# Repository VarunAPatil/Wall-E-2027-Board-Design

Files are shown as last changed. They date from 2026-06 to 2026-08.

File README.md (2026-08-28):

# Wall-E-2027-Board-Design

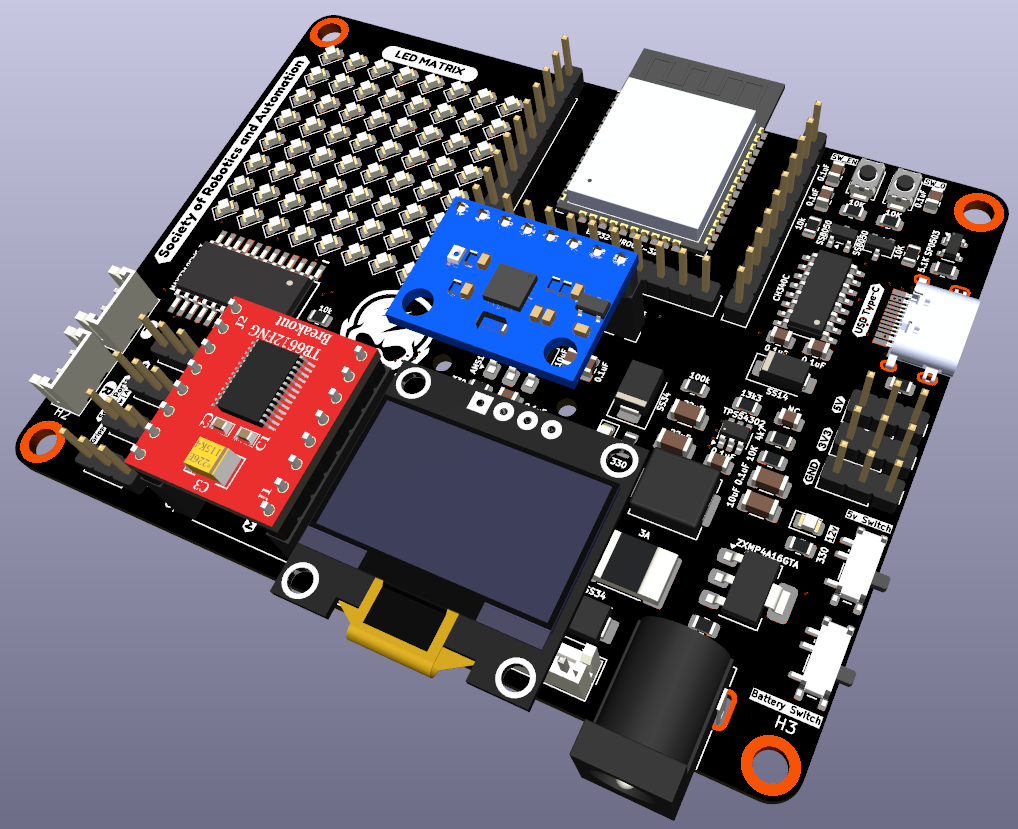
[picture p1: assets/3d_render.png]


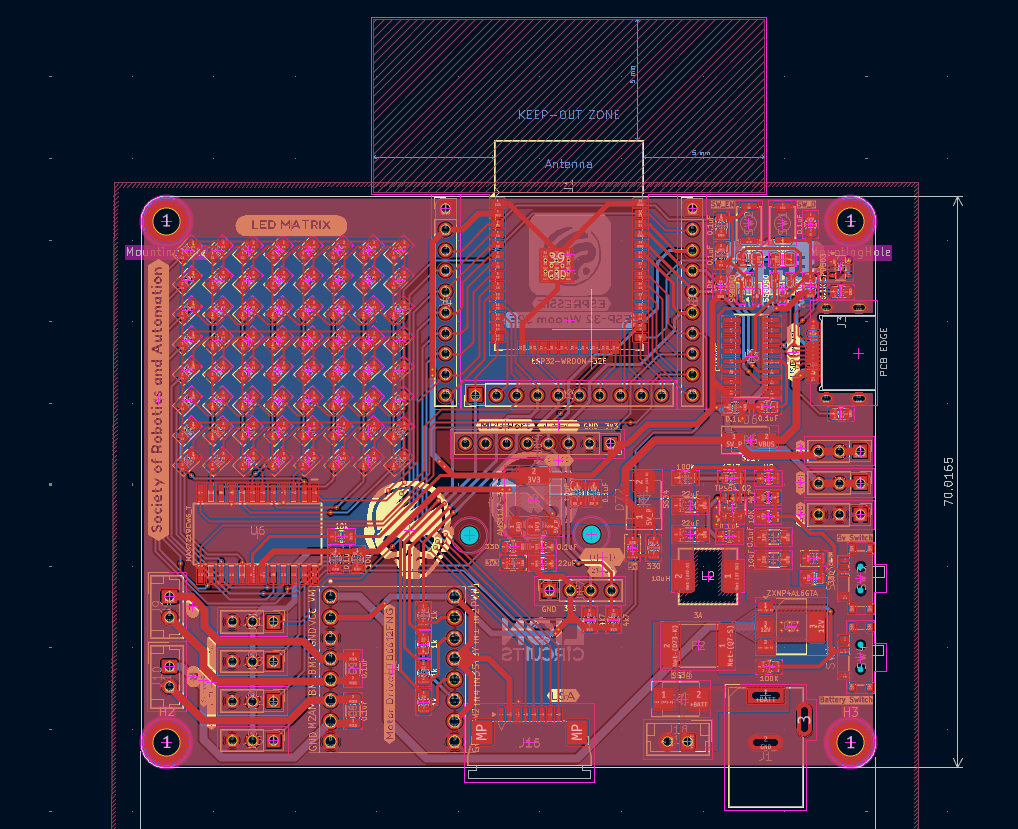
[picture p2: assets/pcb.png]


<!-- PROJECT LOGO -->

[][stars-url]
[][forks-url]
[][issues-url]
[][license-url]

# SRA Board

The SRA board is a development board based on ESP32 with on-board peripherals like a programmable LED matrix, switches, sensor ports for Line Sensor Array and MPU-6050, protection circuit for over-current and reverse voltage, and motor drivers.

## About the Project

- This development board is used for the [Wall-E](https://github.com/SRA-VJTI/Wall-E) and [MARIO](https://github.com/SRA-VJTI/MARIO) workshops conducted by [SRA](https://github.com/SRA-VJTI).
- Designed using KiCAD.

## Getting Started with a Development Board

In general, every development board has the following basic features:

- ### Power Supply Unit
  - Microcontrollers (MCUs) usually run on 3.3V or 5V logic supply voltage while input to a development board is normally 12V for motor and driving/controlling peripheral devices.
  - So, in order to have a single input source, a _power_ section which inter converts this 12V to standard levels like 5V & 3.3V for MCU and sensors is present.This is achieved using a step-down [buck regulator](https://www.youtube.com/watch?v=m8rK9gU30v4).

- ### Motor Driver
  - Motors usually run on 12V and MCU output is generally 5V/3.3V. So, an external motor driver circuitry is required to control motors according to the MCU input.
  - The SRA board use the [TB6612FNG](./datasheets/TB6612FNG_motor_driver.pdf) Motor Driver, which is a MOS-based H-Bridge motor driver.

- ### Sensor Port
  - According to the external sensor types, usually development boards have onboard sensor ports where the sensors can be connected easily. [LSA - Line Sensor Array]() and [MPU- Motion Processing Unit]() have on-board connection ports.
  - Easily available and efficient [JST XH connectors](https://en.wikipedia.org/wiki/JST_connector).
  - Previous versions used bulky [FRC connectors](<https://www.sunrom.com/c/frc-idc-flat-cable-box-header#:~:text=FRC%20(Flat%20Ribon%20Cable)%20are,from%206%20to%2064%20pins.>)

- ### Protection against [Reverse Voltage](https://www.google.com/url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)
  - The SRA Boards use diodes for reverse voltage protection in the power-line.
  - 12V Motor line and power regulated line have been separated with [SS34](./datasheets/ss34_3A_schottky_diode.pdf) and [SS54](./datasheets/ss24_2A_schottky_diode.pdf) schottky diodes respectively.

- ### Protection against [Over Current](https://www.baypower.com/blog/what-is-overcurrent-protection/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,of%20a%20piece%20of%20equipment.)
  - This is done by PTC Resettable Fuses.
- ### Programmable Switches and LEDs
  - Every development board should have some programmable switches and LEDs for testing, control and debugging purposes.
  - The SRA Board features a 8x8 LED matrix (64 LEDs total) controlled via MAX7219, which provides enhanced debugging capabilities and expressive visual feedback while reducing GPIO usage compared to discrete LEDs.

- ### Power Switch
  - All versions have a power switch for the motor driver, using which power supply to the motor driver can be toggled. Similarly, there was a switch for the ESP32 MCU.

- ### **Compatiblity of SRA Board with Battery [3- 3.3V 2500mAh Batteries](https://robu.in/product/bak-nmc-18650-2500mah-8c-lithium-ion-battery/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)**
  - The SRA Board is compatible with **3-cell (3S) Lithium-ion battery packs** which use an external **[BMS (Battery Management System)](https://robu.in/product/3s-10a-12v-18650-lithium-battery-charger-board-protection-module/)**.
  - The BMS helps maintain safe operating voltages and disconnects the battery when the voltage drops below a safe limit.
  - It also ensures balanced charging and discharging of the three cells, improving the overall health and lifetime of the battery pack.

- ### **LD33 (3.3V) to [AMS1117](http://www.advanced-monolithic.com/pdf/ams1117.pdf)**:
  - Older editions used the **LD33 IC** to step down from 5V to 3.3V.
  - This was later replaced with the **AMS1117-3.3 LDO**, which is more compact and widely used for stable 3.3V regulation.
  - (_AMS1117 is also used on the ESP32-DevKitC V4 module._)

- ### **Reverse voltage protection: Diodes to P-MOSFET**
  - Diodes placed in series with the power line introduce voltage drop and power loss compared to a **P-MOSFET based protection circuit**.
  - Due to the higher current requirements of the motors, managing diode size and current rating became difficult.
  - Therefore, earlier versions used a **P-MOSFET based reverse polarity protection circuit**, which is more efficient and can handle higher currents.

## Contributors

- [Varun Patil](https://github.com/VarunAPatil): _Designer_
- [Omkar Nanajkar](https://github.com/nomkar24): _Designer_
<!-- ACKNOWLEDGEMENTS AND REFERENCES -->

## License

- Distributed under the [MIT License](https://github.com/SRA-VJTI/sraboard-hardware-design/blob/master/LICENSE).

[forks-shield]: https://img.shields.io/github/forks/SRA-VJTI/sra-board-hardware-design
[forks-url]: https://github.com/SRA-VJTI/sra-board-hardware-design/network/members
[stars-shield]: https://img.shields.io/github/stars/SRA-VJTI/sra-board-hardware-design
[stars-url]: https://github.com/SRA-VJTI/sra-board-hardware-design/stargazers
[issues-shield]: https://img.shields.io/github/issues/SRA-VJTI/sra-board-hardware-design
[issues-url]: https://github.com/SRA-VJTI/sra-board-hardware-design/issues
[license-shield]: https://img.shields.io/github/license/SRA-VJTI/sra-board-hardware-design
[license-url]: https://github.com/SRA-VJTI/sra-board-hardware-design/blob/master/LICENSE

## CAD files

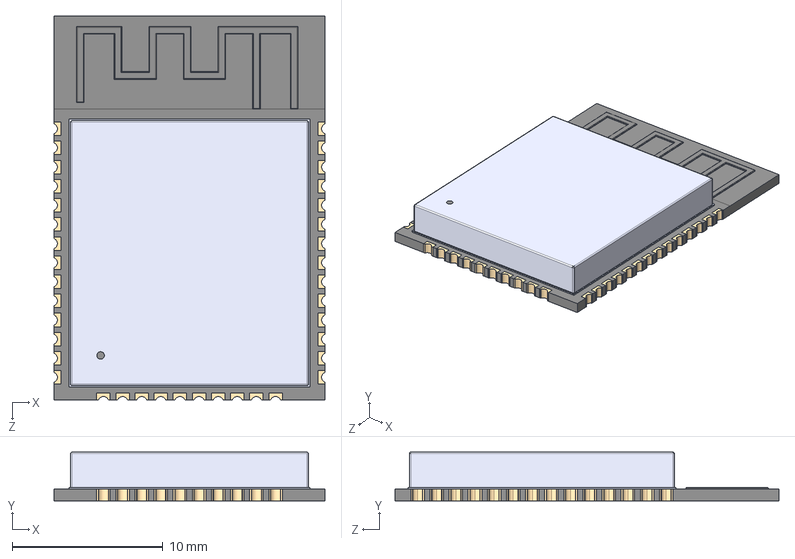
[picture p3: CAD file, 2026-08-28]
3D/ESP32-WROOM-32E.STEP
18.0 x 3.25 x 25.5 mm

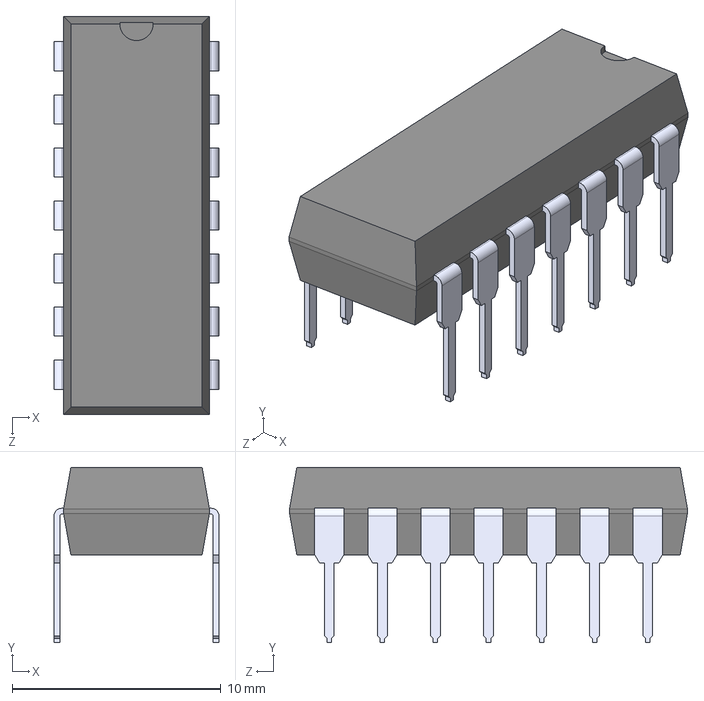
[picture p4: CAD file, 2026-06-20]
MAX7219/MAX7219.step
7.90 x 8.38 x 19.1 mm

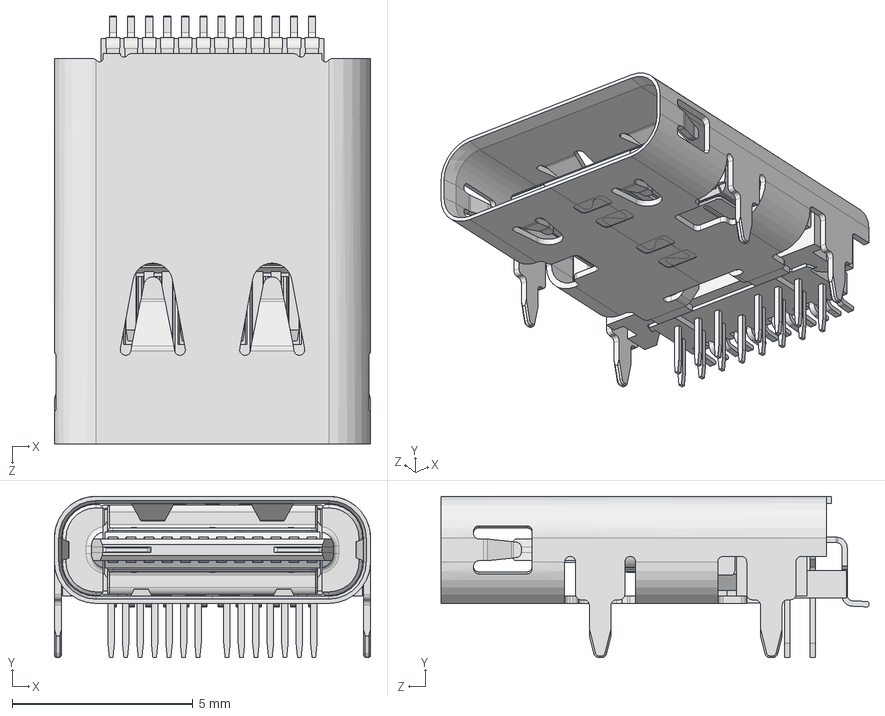
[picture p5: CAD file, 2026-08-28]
3D/217B-AG01--3DModel-STEP-1070261.STEP
8.74 x 4.46 x 11.8 mm

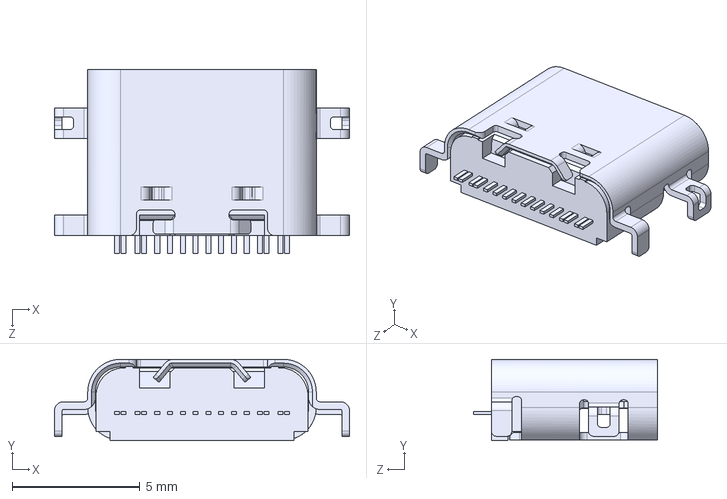
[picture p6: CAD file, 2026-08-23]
3D/GSB1C4621DS1HR.step
11.5 x 3.18 x 7.20 mm

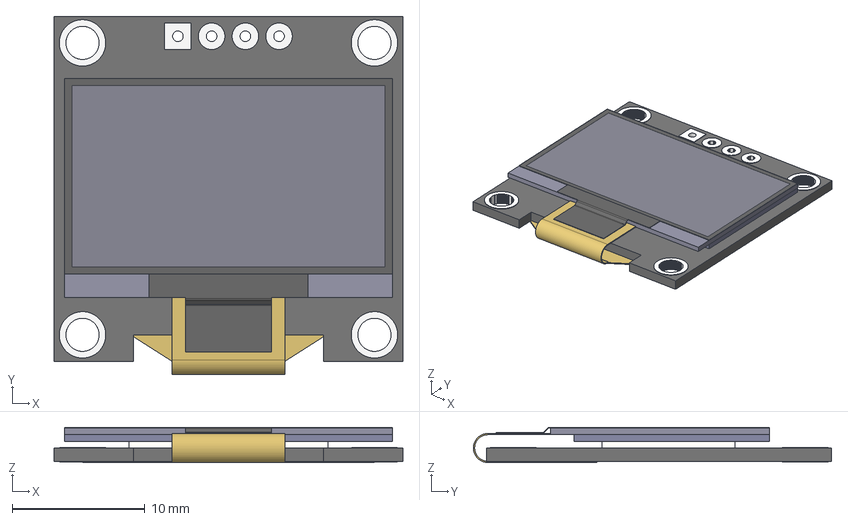
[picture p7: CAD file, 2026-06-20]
3D/OLED.step
26.3 x 27.0 x 2.65 mm
Body - PCB
Body - Back Panel
Body - Adhesive Pad
Body - Front Panel
Body - Flex Connector Bend
Body - Flex Connector Terminals
Body - Black Tape
Body - Protective Foil
Body - Screen Border
Extrude - Annular Rings

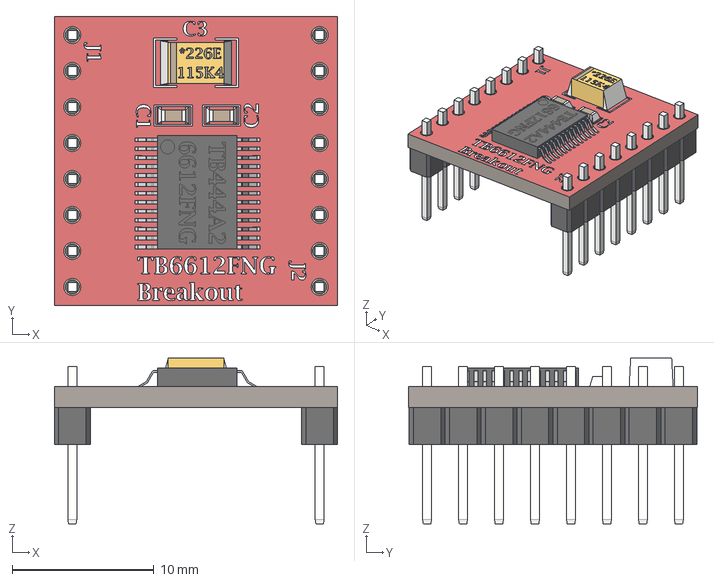
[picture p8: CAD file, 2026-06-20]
3D/MotorDriver.step
20.0 x 20.4 x 11.7 mm
8x1 male header pins x 2

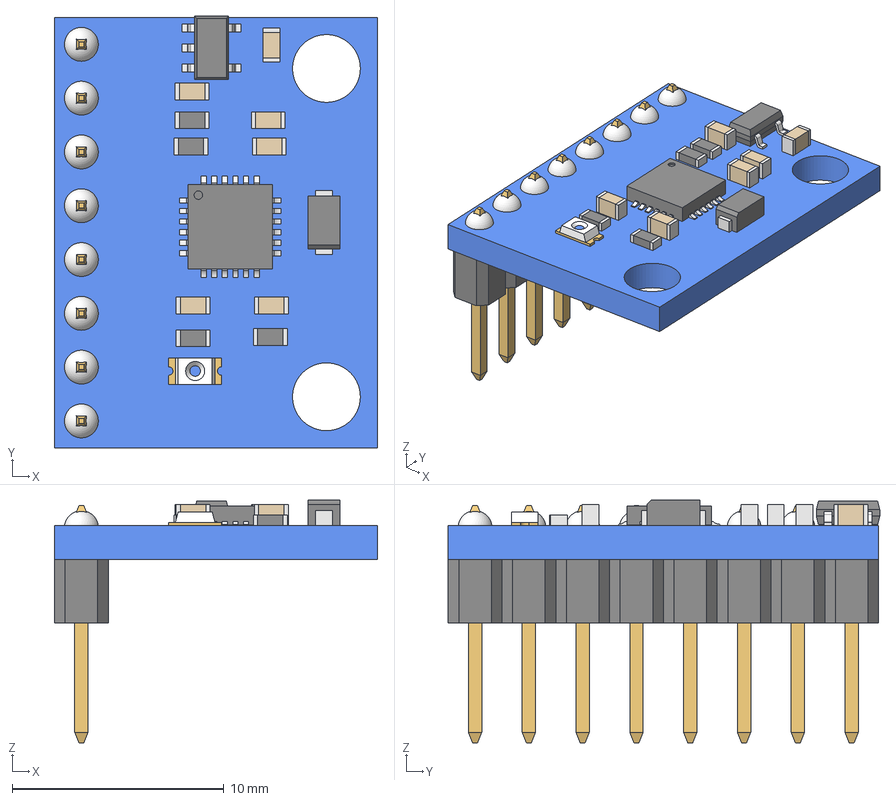
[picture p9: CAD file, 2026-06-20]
3D/MPU6050Module.step
15.3 x 20.4 x 11.5 mm
Board_001
SOT25_001
0603 Capacitor_001
0603 Capacitor_002
0603 Capacitor_003
0603 Capacitor_004
0603 Capacitor_005
0603 Capacitor_006
0603 Resistor_001
0603 Resistor_002
0603 Resistor_003
0603 Resistor_004
SM LED_001
Diode 2_001
24 QFN_001
1x8 Male Header_001

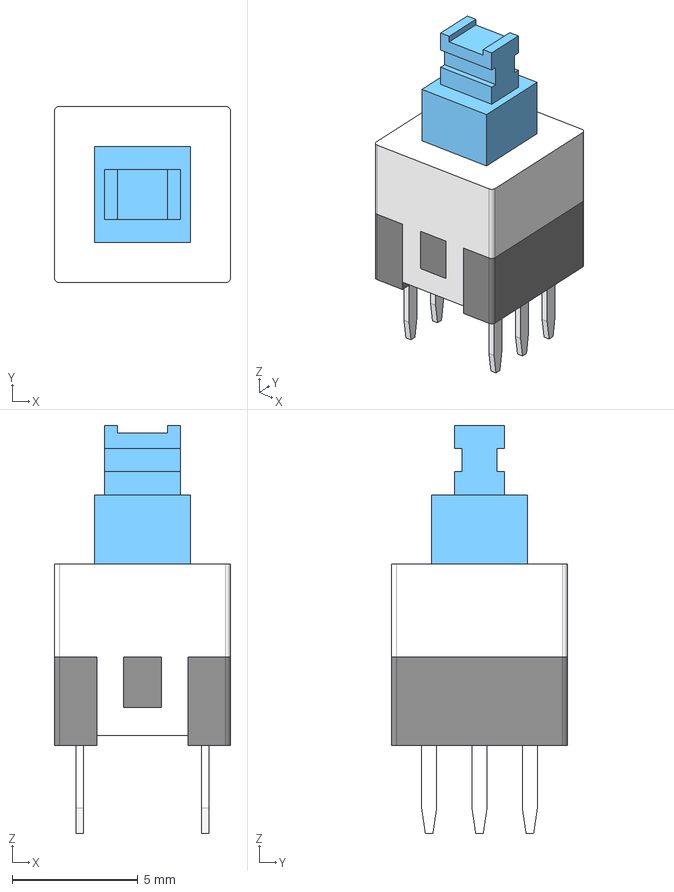
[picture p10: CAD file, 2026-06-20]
3D/DPDTSwitch.step
7.00 x 7.00 x 16.2 mm

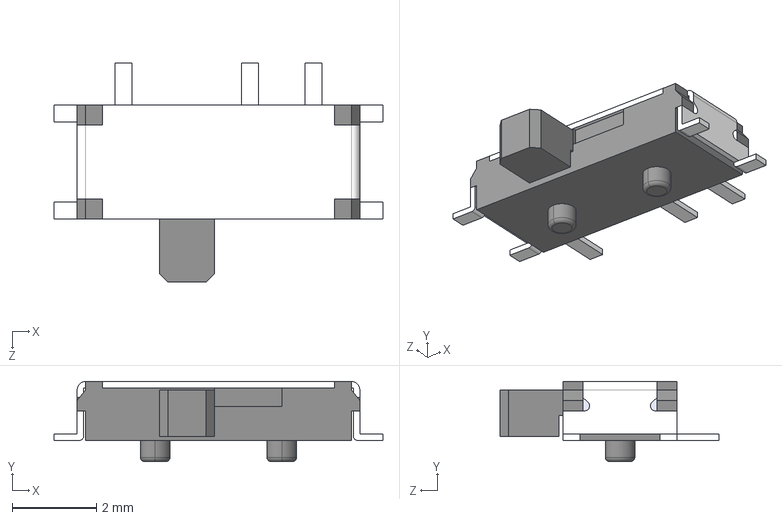
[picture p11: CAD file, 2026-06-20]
3D/MSK12C02.stp
7.80 x 1.90 x 5.20 mm

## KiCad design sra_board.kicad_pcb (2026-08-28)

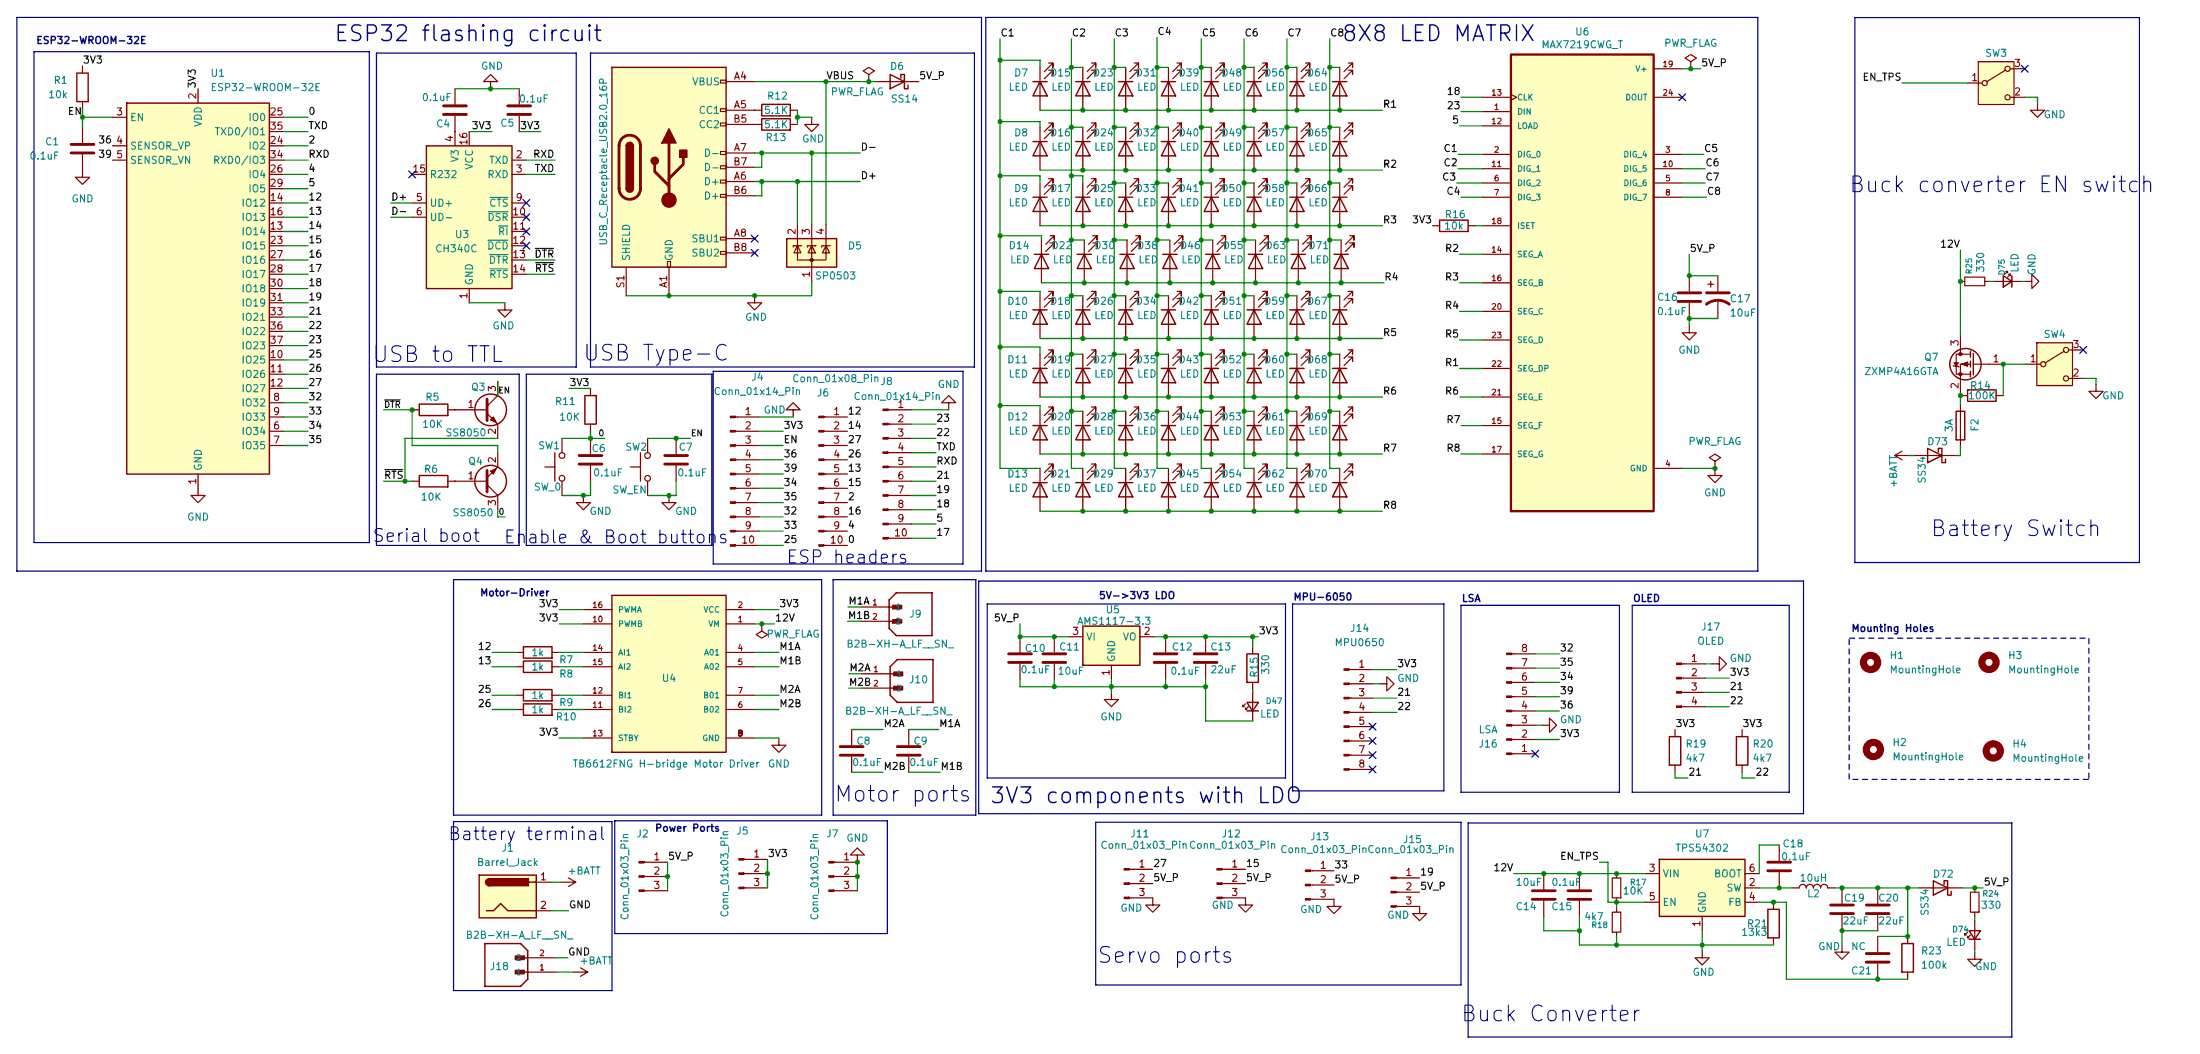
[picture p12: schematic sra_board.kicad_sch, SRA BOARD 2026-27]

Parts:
C1, C4, C5, C6, C7, C10, C12, C16, C18: 0.1uF; C_0805_2012Metric
C8, C9, C15: 0.1uF; C_1206_3216Metric
C11, C17: 10uF; C_0805_2012Metric
C13: 22uF; C_0805_2012Metric
C14: 10uF; C_1206_3216Metric
C19, C20: 22uF; C_1206_3216Metric
C21: NC; C_0805_2012Metric
D5: SP0503; SOT-143
D6: SS14; D_SMA
D7, D8, D9, D10, D11, D12, D13, D14, D15, D16, D17, D18, D19, D20, D21, D22, D23, D24, D25, D26, D27, D28, D29, D30, D31, D32, D33, D34, D35, D36, D37, D38, D39, D40, D41, D42, D43, D44, D45, D46, D47, D48, D49, D50, D51, D52, D53, D54, D55, D56, D57, D58, D59, D60, D61, D62, D63, D64, D65, D66, D67, D68, D69, D70, D71, D74, D75: LED; LED_0805_2012Metric
D72, D73: SS34; D_SMB
F2: 3A; Fuse_2920_7451Metric
H1, H2, H3, H4: MountingHole; MountingHole_3.2mm_M3_DIN965_Pad_TopOnly
J1: Barrel_Jack; BarrelJack_Wuerth_6941xx301002
J2, J5, J7, J11, J12, J13, J15: Conn_01x03_Pin; PinHeader_1x03_P2.54mm_Vertical
J3: USB_C_Receptacle_USB2.0_16P; AMPHENOL_GSB1C4621DS1HR
J4, J8: Conn_01x14_Pin; PinHeader_1x10_P2.54mm_Vertical
J6: Conn_01x08_Pin; PinHeader_1x10_P2.54mm_Vertical
J9, J10, J18: B2B-XH-A_LF__SN_; JST_EH_B2B-EH-A_1x02_P2.50mm_Vertical; PARTREV N/A
J14: MPU0650; PinSocket_1x08_P2.54mm_Vertical
J16: LSA; JUSHUO_AFA07-S08FCA-00_1x8-1MP_P1.0mm_Horizontal
J17: OLED; PinSocket_1x04_P2.54mm_Vertical
L2: 10uH; L_Sunlord_MWSA0603S
Q3, Q4: SS8050; SOT-23
Q7: ZXMP4A16GTA; SOT-223
R1, R16: 10k; R_0805_2012Metric
R5, R6, R11, R17: 10K; R_0805_2012Metric
R7, R8, R9, R10: 1k; R_0805_2012Metric
R12, R13: 5.1K; R_0805_2012Metric
R14: 100K; R_0805_2012Metric
R15, R24, R25: 330; R_0805_2012Metric
R18, R19, R20: 4k7; R_0805_2012Metric
R21: 13k3; R_0805_2012Metric
R23: 100k; R_0805_2012Metric
SW1: SW_0; SW_Push_SPST_NO_Alps_SKRK
SW2: SW_EN; SW_Push_SPST_NO_Alps_SKRK
SW3, SW4: SW_Wuerth_450301014042; SW_SPDT_Shouhan_MSK12C02
U1: ESP32-WROOM-32E; ESP32-WROOM-32D
U3: CH340C; SOIC-16_3.9x9.9mm_P1.27mm
U4: TB6612FNG H-bridge Motor Driver; MODULE_ROB-14450
U5: AMS1117-3.3; SOT-223-3_TabPin2
U6: MAX7219CWG_T; SOIC24
U7: TPS54302; SOT-23-6

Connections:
+BATT: D73.2 (A), J1.1, J18.1
/0: C6.2, J6.10, Q4.3, R11.1, SW1.2, U1.25 (IO0)
/2: J6.7, U1.24 (IO2)
/3V3: C5.1, C12.1, C13.1, J4.2, J5.1, J5.2, J5.3, J14.1, J16.2, J17.2, R1.1, R11.2, R15.1, R16.1, R19.1, R20.1, U1.2 (VDD), U3.16 (VCC), U4.2 (VCC), U4.10 (PWMB), U4.13 (STBY), U4.16 (PWMA), U5.2 (VO)
/4: J6.9, U1.26 (IO4)
/5: J8.9, U1.29 (IO5), U6.12 (LOAD)
/5V_P: C10.1, C11.1, C16.1, C17.1, D6.1 (K), D72.1 (K), J2.1, J2.2, J2.3, J11.2, J12.2, J13.2, J15.2, R24.2, U5.3 (VI), U6.19 (V+)
/12: J6.1, R7.1, U1.14 (IO12)
/12V: C14.1, C15.1, Q7.3 (D), R17.2, R25.2, U4.1 (VM), U7.3 (VIN)
/13: J6.5, R8.1, U1.16 (IO13)
/14: J6.2, U1.13 (IO14)
/15: J6.6, J12.1, U1.23 (IO15)
/16: J6.8, U1.27 (IO16)
/17: J8.10, U1.28 (IO17)
/18: J8.8, U1.30 (IO18), U6.13 (CLK)
/19: J8.7, J15.1, U1.31 (IO19)
/21: J8.6, J14.3, J17.3, R19.2, U1.33 (IO21)
/22: J8.3, J14.4, J17.4, R20.2, U1.36 (IO22)
/23: J8.2, U1.37 (IO23), U6.1 (DIN)
/25: J4.10, R9.1, U1.10 (IO25)
/26: J6.4, R10.1, U1.11 (IO26)
/27: J6.3, J11.1, U1.12 (IO27)
/32: J4.8, J16.8, U1.8 (IO32)
/33: J4.9, J13.1, U1.9 (IO33)
/34: J4.6, J16.6, U1.6 (IO34)
/35: J4.7, J16.7, U1.7 (IO35)
/36: J4.4, J16.4, U1.4 (SENSOR_VP)
/39: J4.5, J16.5, U1.5 (SENSOR_VN)
/C1: D7.1 (K), D8.1 (K), D9.1 (K), D10.1 (K), D11.1 (K), D12.1 (K), D13.1 (K), D14.1 (K), U6.2 (DIG_0)
/C2: D15.1 (K), D16.1 (K), D17.1 (K), D18.1 (K), D19.1 (K), D20.1 (K), D21.1 (K), D22.1 (K), U6.11 (DIG_1)
/C3: D23.1 (K), D24.1 (K), D25.1 (K), D26.1 (K), D27.1 (K), D28.1 (K), D29.1 (K), D30.1 (K), U6.6 (DIG_2)
/C4: D31.1 (K), D32.1 (K), D33.1 (K), D34.1 (K), D35.1 (K), D36.1 (K), D37.1 (K), D38.1 (K), U6.7 (DIG_3)
/C5: D39.1 (K), D40.1 (K), D41.1 (K), D42.1 (K), D43.1 (K), D44.1 (K), D45.1 (K), D46.1 (K), U6.3 (DIG_4)
/C6: D48.1 (K), D49.1 (K), D50.1 (K), D51.1 (K), D52.1 (K), D53.1 (K), D54.1 (K), D55.1 (K), U6.10 (DIG_5)
/C7: D56.1 (K), D57.1 (K), D58.1 (K), D59.1 (K), D60.1 (K), D61.1 (K), D62.1 (K), D63.1 (K), U6.5 (DIG_6)
/C8: D64.1 (K), D65.1 (K), D66.1 (K), D67.1 (K), D68.1 (K), D69.1 (K), D70.1 (K), D71.1 (K), U6.8 (DIG_7)
/D+: D5.2 (K), J3.A6 (D+), J3.B6 (D+), U3.5 (UD+)
/D-: D5.3 (K), J3.A7 (D-), J3.B7 (D-), U3.6 (UD-)
/EN: C1.1, C7.2, J4.3, Q3.3, R1.2, SW2.2, U1.3 (EN)
/EN_TPS: R17.1, R18.2, SW3.1 (B), U7.5 (EN)
/M1A: C9.1, J9.1, U4.4 (A01)
/M1B: C9.2, J9.2, U4.5 (A02)
/M2A: C8.1, J10.1, U4.7 (B01)
/M2B: C8.2, J10.2, U4.6 (B02)
/R1: D7.2 (A), D15.2 (A), D23.2 (A), D31.2 (A), D39.2 (A), D48.2 (A), D56.2 (A), D64.2 (A), U6.22 (SEG_DP)
/R2: D8.2 (A), D16.2 (A), D24.2 (A), D32.2 (A), D40.2 (A), D49.2 (A), D57.2 (A), D65.2 (A), U6.14 (SEG_A)
/R3: D9.2 (A), D17.2 (A), D25.2 (A), D33.2 (A), D41.2 (A), D50.2 (A), D58.2 (A), D66.2 (A), U6.16 (SEG_B)
/R4: D14.2 (A), D22.2 (A), D30.2 (A), D38.2 (A), D46.2 (A), D55.2 (A), D63.2 (A), D71.2 (A), U6.20 (SEG_C)
/R5: D10.2 (A), D18.2 (A), D26.2 (A), D34.2 (A), D42.2 (A), D51.2 (A), D59.2 (A), D67.2 (A), U6.23 (SEG_D)
/R6: D11.2 (A), D19.2 (A), D27.2 (A), D35.2 (A), D43.2 (A), D52.2 (A), D60.2 (A), D68.2 (A), U6.21 (SEG_E)
/R7: D12.2 (A), D20.2 (A), D28.2 (A), D36.2 (A), D44.2 (A), D53.2 (A), D61.2 (A), D69.2 (A), U6.15 (SEG_F)
/R8: D13.2 (A), D21.2 (A), D29.2 (A), D37.2 (A), D45.2 (A), D54.2 (A), D62.2 (A), D70.2 (A), U6.17 (SEG_G)
/RXD: J8.5, U1.34 (RXD0/IO3), U3.2 (TXD)
/TXD: J8.4, U1.35 (TXD0/IO1), U3.3 (RXD)
/VBUS: D5.4 (K), D6.2 (A), J3.A4 (VBUS), J3.A9 (VBUS), J3.B4 (VBUS), J3.B9 (VBUS)
/~DTR: Q4.2, R5.1, U3.13 (~DTR)
/~RTS: Q3.2, R6.1, U3.14 (~RTS)
GND: C1.2, C4.2, C5.2, C6.1, C7.1, C10.2, C11.2, C12.2, C13.2, C14.2, C15.2, C16.2, C17.2, C19.2, C20.2, D5.1 (A), D47.1 (K), D74.1 (K), D75.1 (K), J1.2, J3.A1 (GND), J3.A12 (GND), J3.B1 (GND), J3.B12 (GND), J3.S1 (SHIELD), J4.1, J7.1, J7.2, J7.3, J8.1, J11.3, J12.3, J13.3, J14.2, J15.3, J16.3, J17.1, J18.2, R12.2, R13.2, R18.1, R21.2, SW1.1, SW2.1, SW3.2 (C), SW4.2 (C), U1.1 (GND), U1.15 (GND), U1.38 (GND), U1.39 (GND), U3.1 (GND), U4.3 (GND), U4.8 (GND), U4.9 (GND), U5.1 (GND), U6.4 (GND), U6.9 (GND), U7.1 (GND)
unnamed: D47.2 (A), R15.2
unnamed: C19.1, C20.1, C21.1, D72.2 (A), L2.2, R23.1
unnamed: D73.1 (K), F2.2
unnamed: D74.2 (A), R24.1
unnamed: D75.2 (A), R25.1
unnamed: J3.A5 (CC1), R12.1
unnamed: J3.B5 (CC2), R13.1
unnamed: Q3.1, R5.2
unnamed: Q4.1, R6.2
unnamed: Q7.1 (G), R14.1, SW4.1 (B)
unnamed: F2.1, Q7.2 (S), R14.2
unnamed: C4.1, U3.4 (V3)
unnamed: R7.2, U4.14 (AI1)
unnamed: R8.2, U4.15 (AI2)
unnamed: R9.2, U4.12 (BI1)
unnamed: R10.2, U4.11 (BI2)
unnamed: R16.2, U6.18 (ISET)
unnamed: C18.1, U7.6 (BOOT)
unnamed: C21.2, R21.1, R23.2, U7.4 (FB)
unnamed: C18.2, L2.1, U7.2 (SW)

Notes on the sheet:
ESP32 flashing circuit
Power Ports
Motor-Driver
5V->3V3 LDO
ESP32-WROOM-32E
USB to TTL
Enable & Boot buttons
Mounting Holes
Buck Converter
8X8 LED MATRIX
Serial boot
ESP headers
MPU-6050
Battery terminal
LSA
OLED
3V3 components with LDO
Battery Switch
USB Type-C
Servo ports
Buck converter EN switch
Motor ports

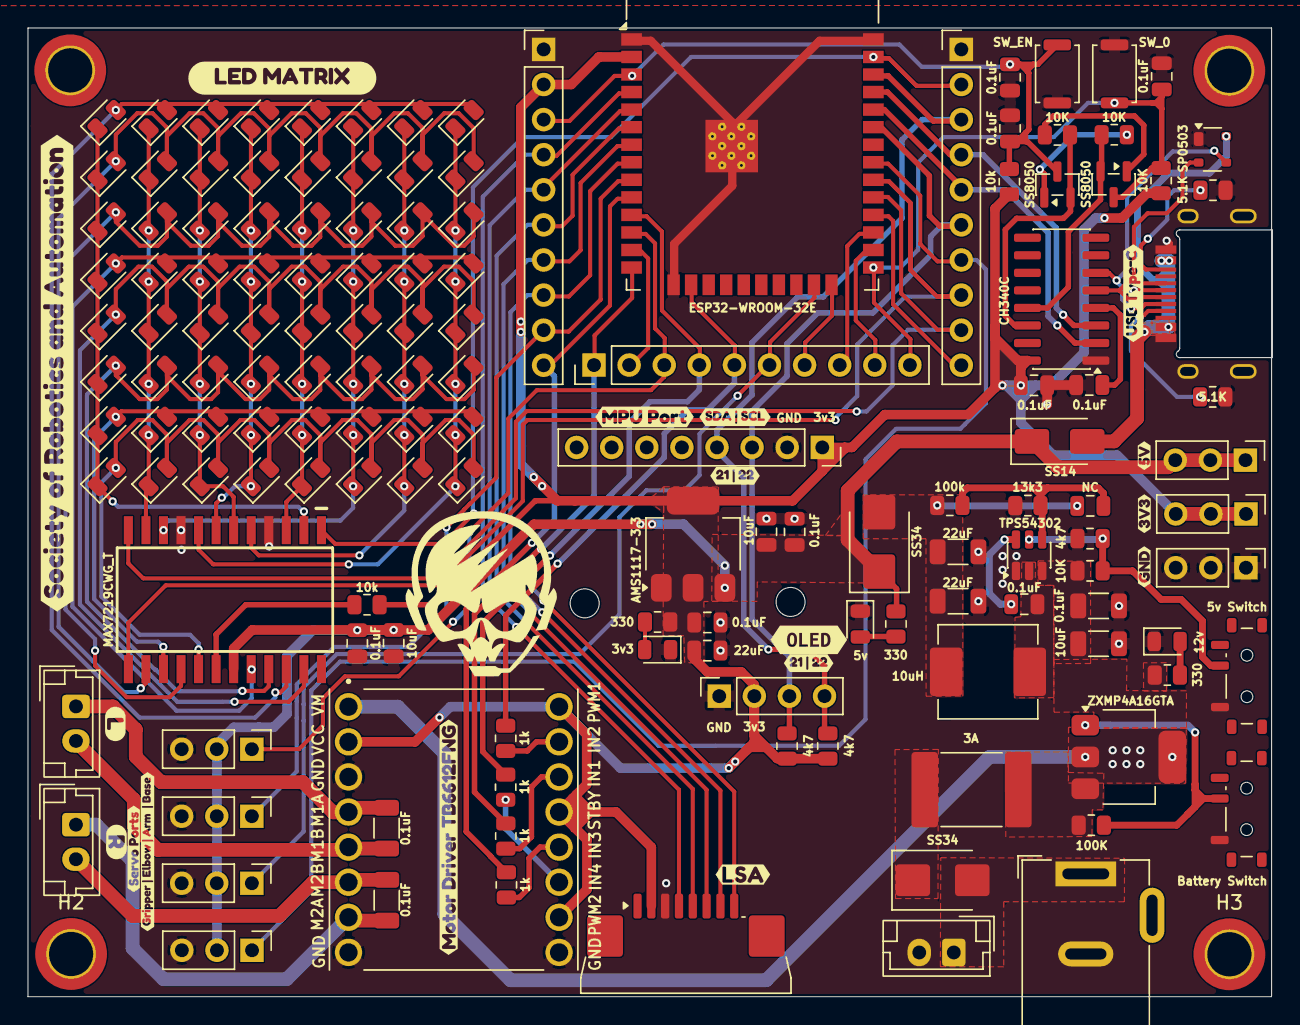
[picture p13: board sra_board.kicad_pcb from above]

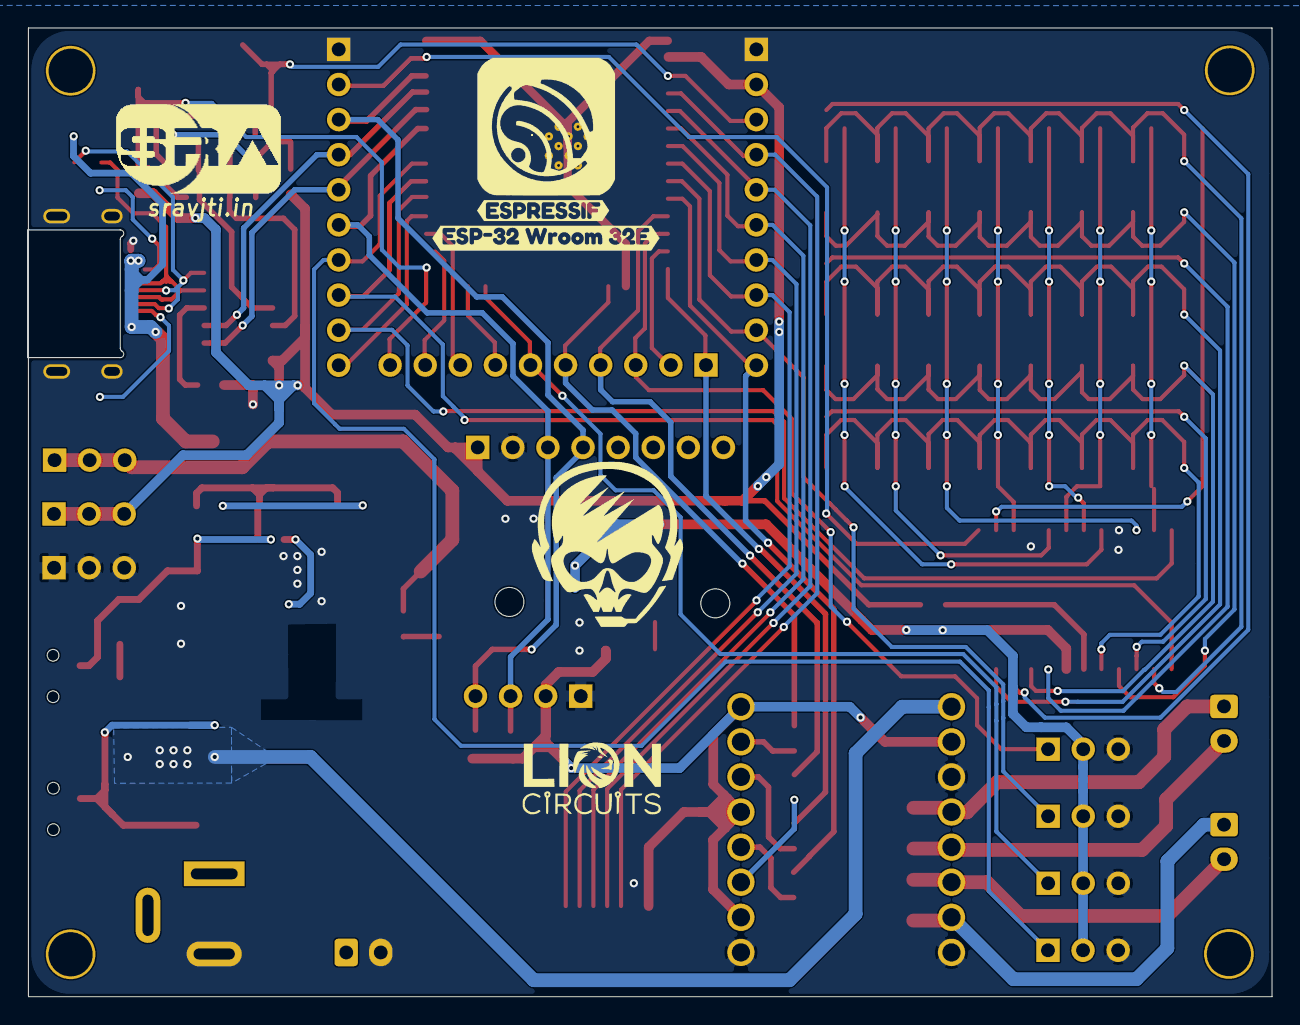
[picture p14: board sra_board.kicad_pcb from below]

Board: 2 copper layers, 90.0 x 70.1 mm, 169 parts (2 on the bottom side), 78 nets.

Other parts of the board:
H5, H6: MountingHole; MountingHole_2.1mm
kibuzzard-6A8B3292: G***; kibuzzard-6A8B3292
kibuzzard-66CD8CDE: G***; kibuzzard-66CD8CDE
kibuzzard-66CD901B: G***; kibuzzard-66CD901B
kibuzzard-68E7F907: G***; kibuzzard-68E7F907
kibuzzard-658F2C3C: G***; kibuzzard-658F2C3C
kibuzzard-668D4F81: G***; kibuzzard-668D4F81
kibuzzard-668FE423: G***; kibuzzard-668FE423
kibuzzard-675FDA6A: G***; kibuzzard-675FDA6A
kibuzzard-675FE5A8, kibuzzard-675FE5A8#2: G***; kibuzzard-675FE5A8
kibuzzard-675FE5B2: G***; kibuzzard-675FE5B2
kibuzzard-6774F4AA: G***; kibuzzard-6774F4AA
kibuzzard-6774F4AE: G***; kibuzzard-6774F4AE
kibuzzard-66914CE9: G***; kibuzzard-66914CE9
kibuzzard-67704CCE: G***; kibuzzard-67704CCE
kibuzzard-67704CDF: G***; kibuzzard-67704CDF
kibuzzard-67704CF4: G***; kibuzzard-67704CF4
kibuzzard-66921043: G***; kibuzzard-66921043
kibuzzard-66923428: G***; kibuzzard-66923428

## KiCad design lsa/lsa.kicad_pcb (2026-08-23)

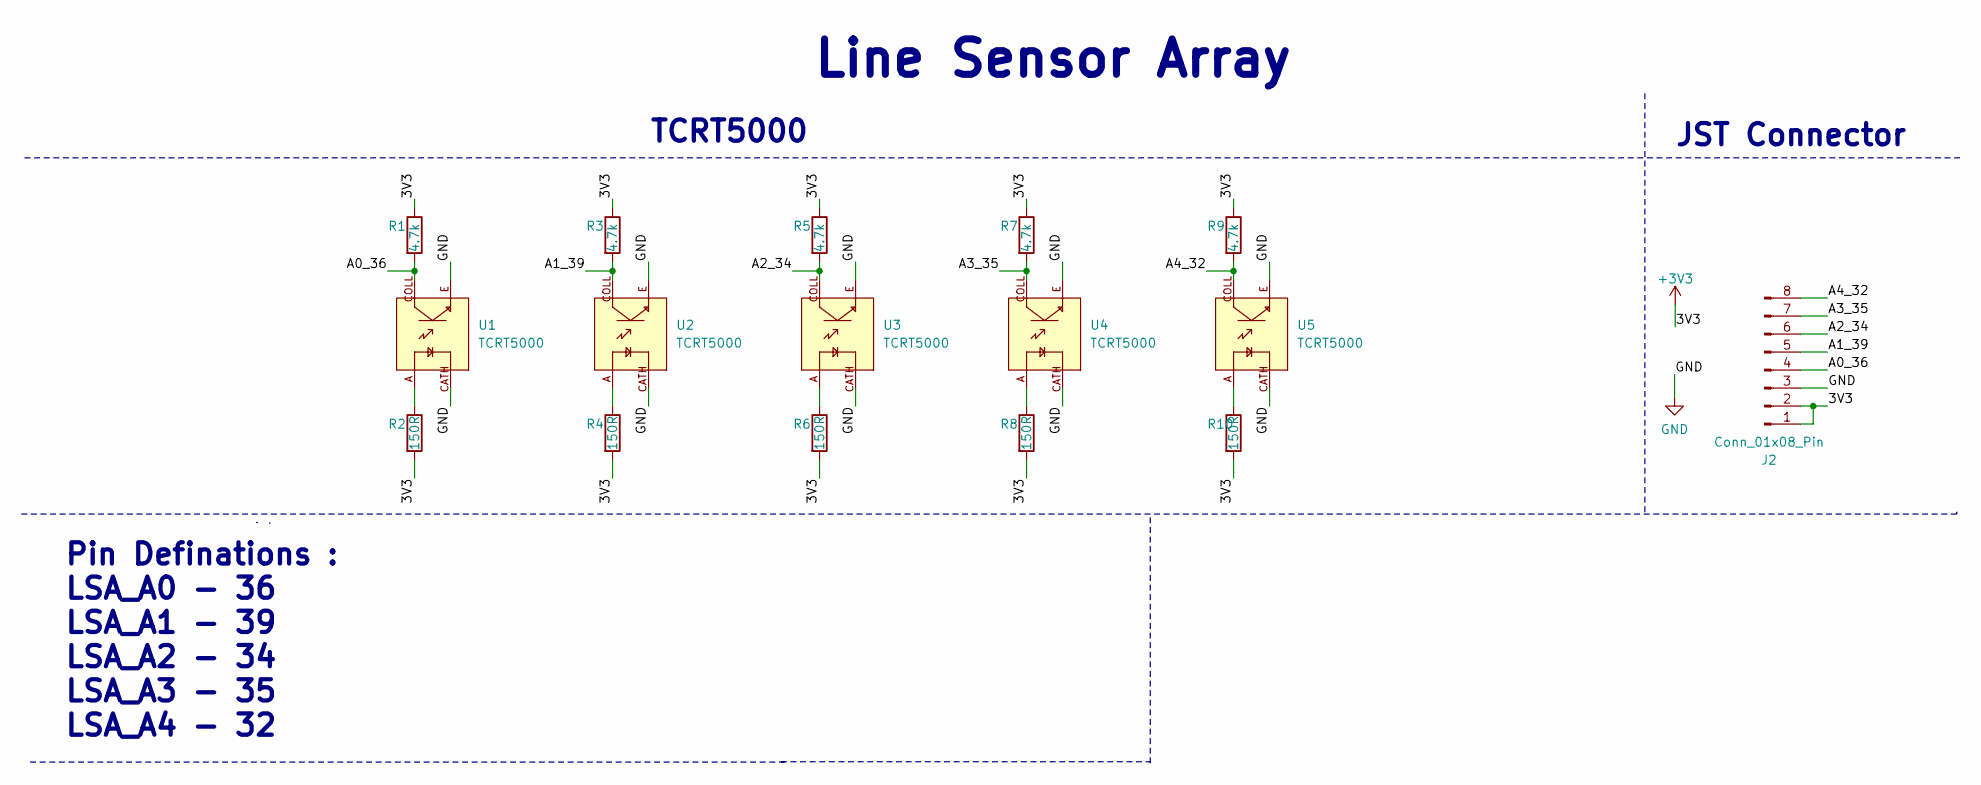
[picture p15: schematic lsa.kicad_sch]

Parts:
J2: Conn_01x08_Pin
R1, R3, R5, R7, R9: 4.7k; R_1206_3216Metric_Pad1.30x1.75mm_HandSolder
R2, R4, R6, R8, R10: 150R; R_1206_3216Metric_Pad1.30x1.75mm_HandSolder
U1, U2, U3, U4, U5: TCRT5000; OPTO_TCRT5000; PARTREV 1.7

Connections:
+3V3: J2.1, J2.2, R1.1, R2.2, R3.1, R4.2, R5.1, R6.2, R7.1, R8.2, R9.1, R10.2
/A0_36: J2.4, R1.2, U1.COLL
/A1_39: J2.5, R3.2, U2.COLL
/A2_34: J2.6, R5.2, U3.COLL
/A3_35: J2.7, R7.2, U4.COLL
/A4_32: J2.8, R9.2, U5.COLL
GND: J2.3, U1.CATH, U1.E, U2.CATH, U2.E, U3.CATH, U3.E, U4.CATH, U4.E, U5.CATH, U5.E
unnamed: R2.1, U1.A
unnamed: R4.1, U2.A
unnamed: R6.1, U3.A
unnamed: R8.1, U4.A
unnamed: R10.1, U5.A

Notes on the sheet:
JST Connector
Line Sensor Array
TCRT5000
Pin Definations : LSA_A0 - 36 LSA_A1 - 39 LSA_A2 - 34 LSA_A3 - 35 LSA_A4 - 32

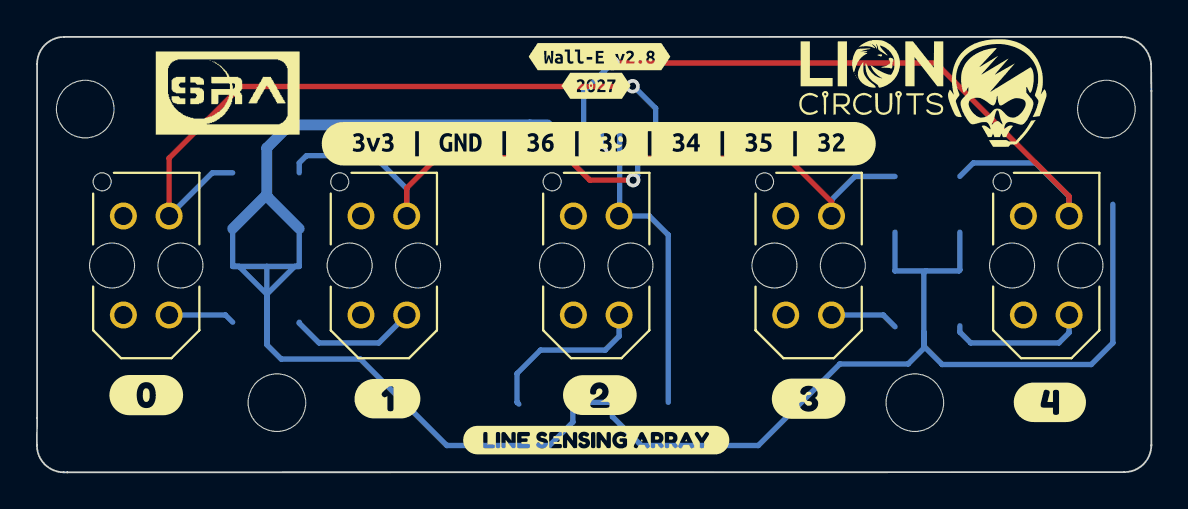
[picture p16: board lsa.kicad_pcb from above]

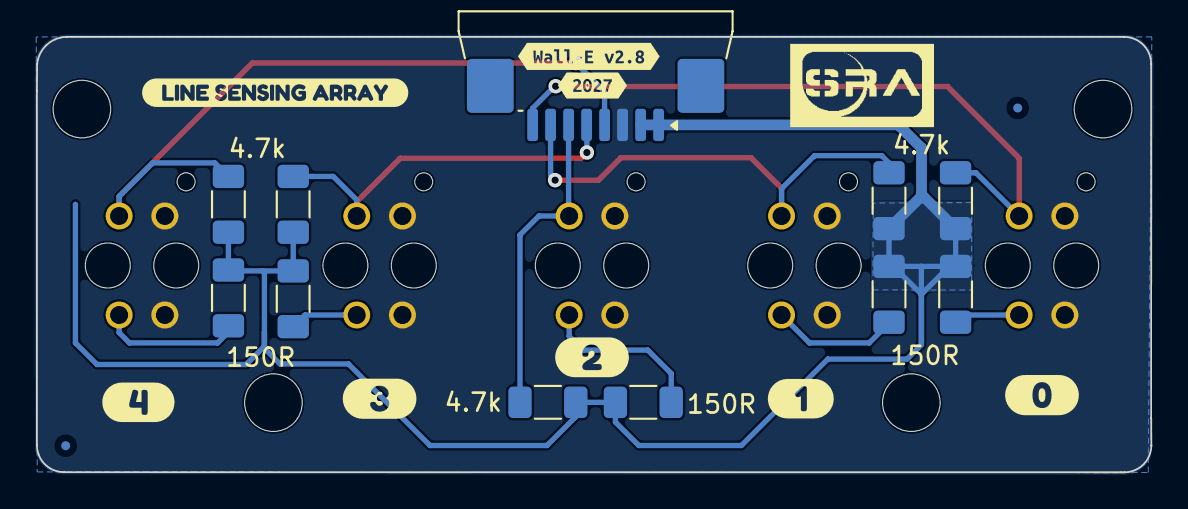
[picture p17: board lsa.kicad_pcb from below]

Board: 2 copper layers, 61.9 x 24.2 mm, 33 parts (19 on the bottom side), 12 nets.

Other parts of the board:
kibuzzard-6A8B4B44: G***; kibuzzard-6A8B4B44
kibuzzard-6A70DDC1, kibuzzard-6A70DDC1#2: G***; kibuzzard-6A70DDC1
kibuzzard-6A70DDE3, kibuzzard-6A70DDE3#2: G***; kibuzzard-6A70DDE3
kibuzzard-672CF9E4, kibuzzard-672CF9E4#2: G***; kibuzzard-672CF9E4
kibuzzard-63708D58, kibuzzard-63708D58#2: G***; kibuzzard-63708D58
kibuzzard-63708D75, kibuzzard-63708D75#2: G***; kibuzzard-63708D75
kibuzzard-63708D85, kibuzzard-63708D85#2: G***; kibuzzard-63708D85
kibuzzard-63708DAF, kibuzzard-63708DAF#2: G***; kibuzzard-63708DAF
kibuzzard-63708DBF, kibuzzard-63708DBF#2: G***; kibuzzard-63708DBF

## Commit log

2026-05-24 added esp32, 8x8 LED Matrix with MAX
    [sra_board.kicad_pcb, sra_board.kicad_sch]
2026-05-29 Added Boot circuit and USB-to-TTL
    [sra_board.kicad_pcb, sra_board.kicad_sch]
2026-05-31 Adding power charging circuit for charging battery on seperate type-c
    [sra_board.kicad_pcb, sra_board.kicad_sch]
2026-05-31 Added rest of components
    [sra_board.kicad_sch]
2026-06-09 Using only one type c
    [sra_board.kicad_pcb, sra_board.kicad_sch]
2026-06-09 Making label correction
    [sra_board.kicad_sch]
2026-06-14 placed half components
    [sra_board.kicad_pcb, sra_board.kicad_sch]
2026-06-20 Adding dependencies for PCB
    [MAX7219.step]
2026-06-20 rough placing of components
    [sra_board.kicad_pcb, sra_board.kicad_sch]
2026-06-20 Placement first draft along with 3D files
    [DPDTSwitch.step, MPU6050Module.step, MSK12C02.stp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]
2026-06-21 Finishing the routing
    [sra_board.kicad_pcb, sra_board.kicad_sch]
2026-07-30 Changing the buck converter IC and adding silkscreen and increasing thickness of traces
    [sra_board.kicad_pcb, sra_board.kicad_sch]
2026-08-01 Changed silkscreen and routing a bit
    [sra_board.kicad_sch]
2026-08-02 Partial placing of components in PCB
    [sra_board.kicad_pcb, sra_board.kicad_sch]
2026-08-10 Partial routing complete
    [sra_board.kicad_pcb, sra_board.kicad_sch]
2026-08-18 Adding new layout of pcb
    [sra_board.kicad_pcb, sra_board.kicad_sch]
2026-08-19 Adding new fully routed PCB without CN3303 and controlling the EN pin of TPS with switch rather than actual power line
    [sra_board.kicad_pcb, sra_board.kicad_sch]
2026-08-23 Making minor fixes in pcb
    [sra_board.kicad_pcb, sra_board.kicad_sch]
2026-08-23 Adding LSA and centering the LSA connector on SRA board
    [lsa.kicad_pcb, lsa.kicad_sch, sra_board.kicad_pcb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]
2026-08-23 Adding new type c footprint and 3D file
    [GSB1C4621DS1HR.step]
2026-08-28 Adding various types of type c for prototyping
    [sra_board.kicad_pcb, sra_board.kicad_sch]
2026-08-28 Adding readme and step files
    [217B-AG01--3DModel-STEP-1070261.STEP, ESP32-WROOM-32E.STEP, sra_board.kicad_pcb]
2026-08-29 changing pin defs and making connections
    [sra_board.kicad_pcb, sra_board.kicad_sch]
2026-09-22 Switching to 10 pin FFC cable on both board and LSA, modifying silkscreen and holes for MPU
2026-10-15 Changing the footprint for boot/reset buttons and adding step file for USB-C
2026-10-15 Document SRA board hardware and workflow
